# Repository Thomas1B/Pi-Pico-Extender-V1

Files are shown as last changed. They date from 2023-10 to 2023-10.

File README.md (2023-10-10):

# Raspberry Pi Pico Extender V1

This is a custom extender board for the Raspberry Pi Pico (https://www.raspberrypi.com/products/raspberry-pi-pico/).

It allows full use of the breadboard when prototyping and the pins labels on top for easier reference. The board also contains a USB-C connection for aux power (3V3 and 5V) if needed for high power components.

The board is designed with the same dimensions as a Pi Hat for easy mounting.

<hr>

 (coming soon!)

<hr>

See `Pi Pico Extender V1 DigiKey BOM.csv` for components list.<br>
See `Pi Pico Extender KiCad BOM.csv` for parts reference.

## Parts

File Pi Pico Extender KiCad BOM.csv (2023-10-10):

"Project:","Pi Pico Extender\Pi Pico Extender.kicad_sch"
"Date:","10/5/2023"
"Tool:","Eeschema 7.0.6"
"BOM Generator:","myScripts\myKiCad_BOM_Maker.py"
"Total Component Count:","13"
"Component Type Count:","12"
"Ref","Qnty","Value","Description","Cmp name","Footprint"
"Component: 1/12:"
"A1","1","RPi_Pico_Riser","RPi Pico Riser, 2 01x20 p2.54mm pinSockets","RPi_Pico_Riser","0_Thomas_Footprints:RPi_Pico Riser"
"Component: 2/12:"
"C1","1","10uF","Unpolarized capacitor","C","Capacitor_SMD:C_0805_2012Metric_Pad1.18x1.45mm_HandSolder"
"Component: 3/12:"
"C2","1","22uF","Unpolarized capacitor","C","Capacitor_SMD:C_0805_2012Metric_Pad1.18x1.45mm_HandSolder"
"Component: 4/12:"
"D1","1","LED","Light emitting diode","LED","LED_SMD:LED_0805_2012Metric_Pad1.15x1.40mm_HandSolder"
"Component: 5/12:"
"D2","1","D_Schottky, 20V 2A","Schottky diode","D_Schottky","Diode_SMD:D_SOD-123F"
"Component: 6/12:"
"J1","1","USBc","USB C Socket- 6 pin","USB C Socket- 6 pin","0_Thomas_Footprints:GCT_USB4125-GF-A_REVA2"
"Component: 7/12:"
"J2","1","Conn_01x02","Generic connector, single row, 01x02","Conn_01x02","Connector_PinHeader_2.54mm:PinHeader_1x02_P2.54mm_Vertical"
"Component: 8/12:"
"J3","1","Conn_02x03_Odd_Even","Generic connector, double row, 02x03, odd/even pin numbering scheme (row 1 odd numbers, row 2 even numbers)","Conn_02x03_Odd_Even","Connector_PinSocket_2.54mm:PinSocket_2x03_P2.54mm_Vertical"
"Component: 9/12:"
"J4, J5","2","Conn_01x20","Generic connector, single row, 01x20","Conn_01x20","Connector_PinSocket_2.54mm:PinSocket_1x20_P2.54mm_Vertical"
"Component: 10/12:"
"R1","1","~300","Resistor","R","Resistor_SMD:R_0805_2012Metric_Pad1.20x1.40mm_HandSolder"
"Component: 11/12:"
"SW1","1","Momentary_Button_4pin","4 pin pushbutton","Momentary_Button_4pin","Button_Switch_THT:SW_PUSH_6mm"
"Component: 12/12:"
"U1","1","AZ1117-3.3","1A 20V Fixed LDO Linear Regulator, 3.3V, SOT-89/SOT-223/TO-220/TO-252/TO-263","AZ1117-3.3","Package_TO_SOT_SMD:SOT-223-3_TabPin2"

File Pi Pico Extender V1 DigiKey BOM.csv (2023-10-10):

Description | Manufacturer | Manufacturer Part Number | Digi-Key Part Number | Unit Price | Quantity | Total Price
RASPBERRY PI PICO W RP2040 | Raspberry Pi | SC0918 | 2648-SC0918CT-ND | 8.6 | 1 | 21.56
WR-PHD 2.54 MM DUAL SOCKET HEADE | Würth Elektronik | 61300621821 | 732-61300621821-ND | 0.59 | 1
CONN HDR 20POS 0.1 TIN PCB | Sullins Connector Solutions | PPTC201LFBN-RC | S7018-ND | 1.78 | 4
CONN HEADER VERT 20POS 2.54MM | Adam Tech | PH1-20-UA | 2057-PH1-20-UA-ND | 0.46 | 2
CONN RCPT TYPE C 6P SMD RA | GCT | USB4125-GF-A | 2073-USB4125-GF-ACT-ND | 0.96 | 1
6 X 6 MM, 7 MM ACTUATOR HEIGHT, | CUI Devices | TS02-66-70-BK-160-LCR-D | 2223-TS02-66-70-BK-160-LCR-D-ND | 0.15 | 1
DIODE SCHOTTKY 20V 2A SOD123F | Nexperia USA Inc. | PMEG2020EH,115 | 1727-3862-1-ND | 0.67 | 1
SWITCH SLIDE SPDT 200MA 30V | E-Switch | EG1218 | EG1903-ND | 1.06 | 1
IC REG LINEAR 3.3V 1A SOT223 | Diodes Incorporated | AZ1117IH-3.3TRG1 | AZ1117IH-3.3TRG1DICT-ND | 0.58 | 1
CAP CER 10UF 25V X5R 0805 | Samsung Electro-Mechanics | CL21A106KAYNNNE | 1276-2891-1-ND | 0.26 | 1
CAP CER 22UF 25V X5R 0805 | Samsung Electro-Mechanics | CL21A226MAYNNNE | 1276-CL21A226MAYNNNECT-ND | 0.36 | 1
LED GREEN CLEAR 0805 SMD | Würth Elektronik | 150080VS75000 | 732-4986-1-ND | 0.29 | 1

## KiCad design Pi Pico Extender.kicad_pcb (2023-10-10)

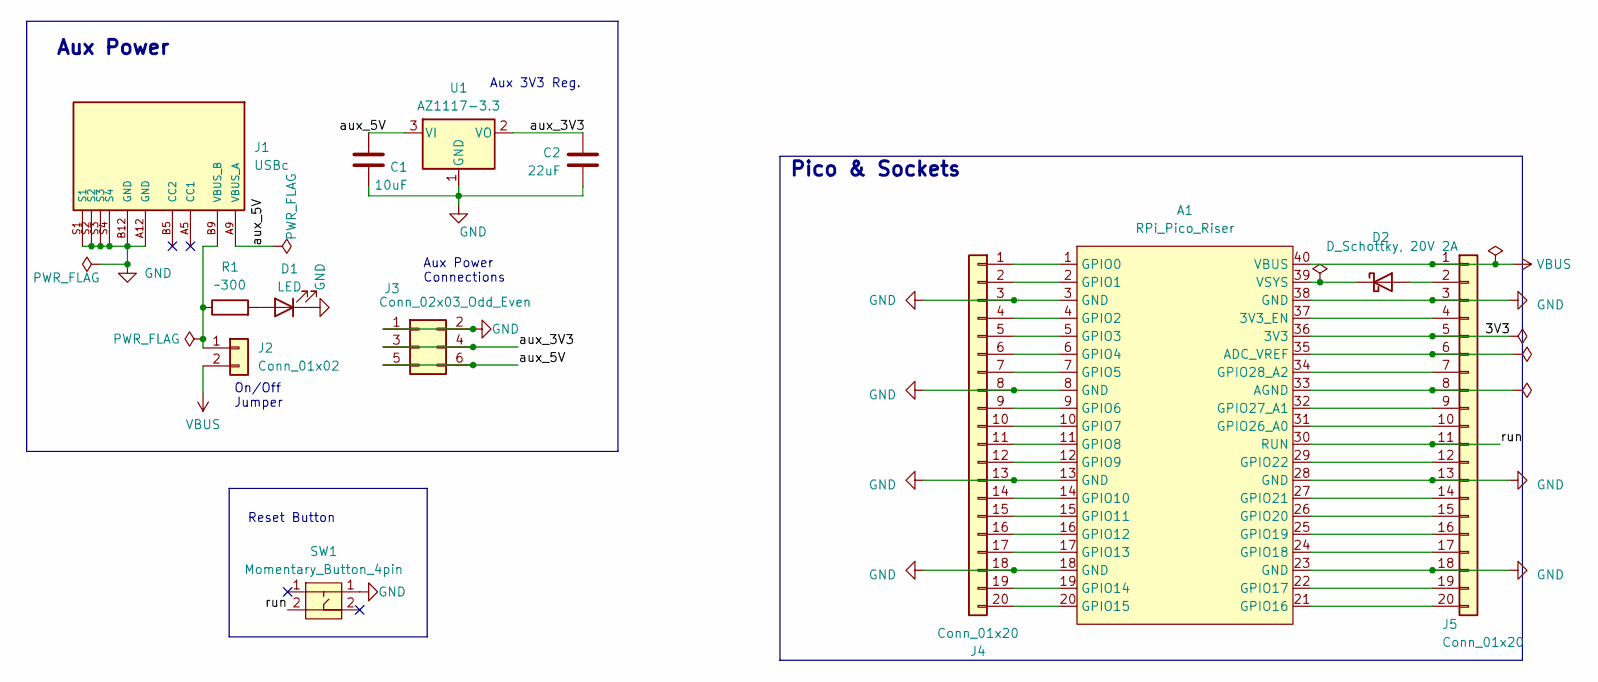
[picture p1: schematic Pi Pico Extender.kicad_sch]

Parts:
A1: RPi_Pico_Riser; RPi_Pico Riser
C1: 10uF; C_0805_2012Metric_Pad1.18x1.45mm_HandSolder
C2: 22uF; C_0805_2012Metric_Pad1.18x1.45mm_HandSolder
D1: LED; LED_0805_2012Metric_Pad1.15x1.40mm_HandSolder
D2: D_Schottky, 20V 2A; D_SOD-123F
J1: USBc; GCT_USB4125-GF-A_REVA2
J2: Conn_01x02; PinHeader_1x02_P2.54mm_Vertical
J3: Conn_02x03_Odd_Even; PinSocket_2x03_P2.54mm_Vertical
J4, J5: Conn_01x20; PinSocket_1x20_P2.54mm_Vertical
R1: ~300; R_0805_2012Metric_Pad1.20x1.40mm_HandSolder
SW1: Momentary_Button_4pin; SW_PUSH_6mm
U1: AZ1117-3.3; SOT-223-3_TabPin2

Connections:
/3V3: A1.36 (3V3), J5.5
/aux_3V3: C2.2, J3.3, J3.4, U1.2 (VO)
/aux_5V: C1.2, J1.A9 (VBUS_A), J3.5, J3.6, U1.3 (VI)
/run: A1.30 (RUN), J5.11, SW1.2
GND: A1.3 (GND), A1.8 (GND), A1.13 (GND), A1.18 (GND), A1.23 (GND), A1.28 (GND), A1.38 (GND), C1.1, C2.1, D1.1 (K), J1.A12 (GND), J1.B12 (GND), J1.S1, J1.S2, J1.S3, J1.S4, J3.1, J3.2, J4.3, J4.8, J4.13, J4.18, J5.3, J5.13, J5.18, SW1.1, U1.1 (GND)
unnamed: A1.37 (3V3_EN), J5.4
unnamed: A1.35 (ADC_VREF), J5.6
unnamed: A1.33 (AGND), J5.8
unnamed: A1.1 (GPIO0), J4.1
unnamed: A1.2 (GPIO1), J4.2
unnamed: A1.4 (GPIO2), J4.4
unnamed: A1.5 (GPIO3), J4.5
unnamed: A1.6 (GPIO4), J4.6
unnamed: A1.7 (GPIO5), J4.7
unnamed: A1.9 (GPIO6), J4.9
unnamed: A1.10 (GPIO7), J4.10
unnamed: A1.11 (GPIO8), J4.11
unnamed: A1.12 (GPIO9), J4.12
unnamed: A1.14 (GPIO10), J4.14
unnamed: A1.15 (GPIO11), J4.15
unnamed: A1.16 (GPIO12), J4.16
unnamed: A1.17 (GPIO13), J4.17
unnamed: A1.19 (GPIO14), J4.19
unnamed: A1.20 (GPIO15), J4.20
unnamed: A1.21 (GPIO16), J5.20
unnamed: A1.22 (GPIO17), J5.19
unnamed: A1.24 (GPIO18), J5.17
unnamed: A1.25 (GPIO19), J5.16
unnamed: A1.26 (GPIO20), J5.15
unnamed: A1.27 (GPIO21), J5.14
unnamed: A1.29 (GPIO22), J5.12
unnamed: A1.31 (GPIO26_A0), J5.10
unnamed: A1.32 (GPIO27_A1), J5.9
unnamed: A1.34 (GPIO28_A2), J5.7
unnamed: A1.39 (VSYS), D2.1 (K)
unnamed: D1.2 (A), R1.2
unnamed: D2.2 (A), J5.2
unnamed: J1.B9 (VBUS_B), J2.1, R1.1
VBUS: A1.40 (VBUS), J2.2, J5.1

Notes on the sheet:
Pico & Sockets
Aux Power
On/Off Jumper
Aux 3V3 Reg.
Reset Button
Aux Power Connections

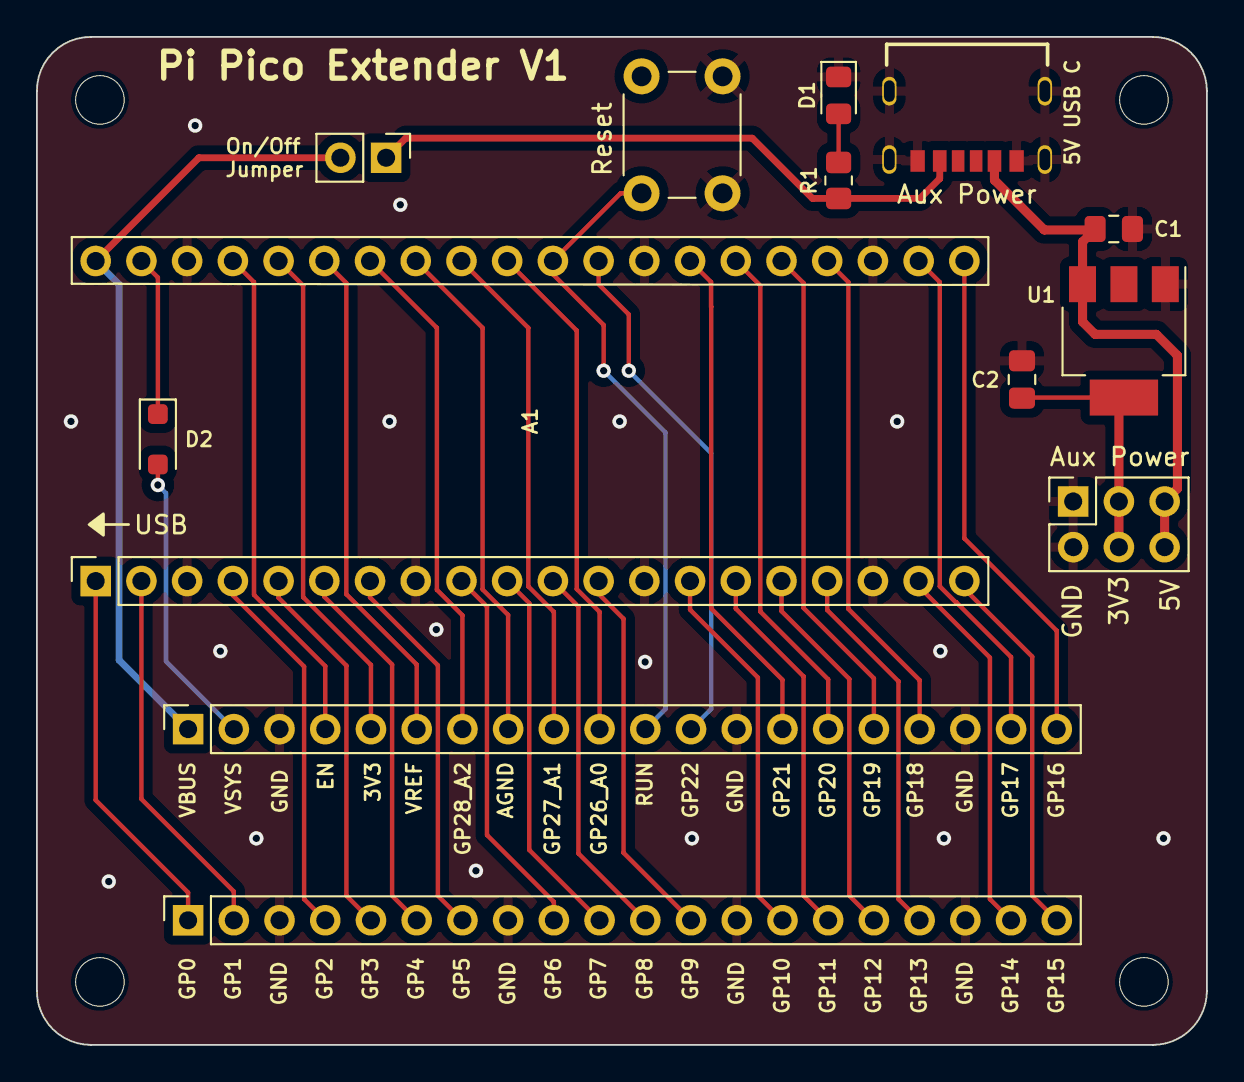
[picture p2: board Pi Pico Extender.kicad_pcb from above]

Board: 2 copper layers, 65.0 x 56.0 mm, 17 parts (0 on the bottom side), 39 nets.

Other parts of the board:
MH1, MH2, MH3, MH4: MountingHole_2.7mm_M2.5
